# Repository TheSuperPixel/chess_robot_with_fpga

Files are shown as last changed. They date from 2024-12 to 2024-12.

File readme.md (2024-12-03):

# FPGA三子棋机器人
## 简介
这是我们用纯Verilog制作的三子棋机器人，参加全国大学生芯片与系统设计大赛FPGA赛道获得一等奖。机器主要由图像识别部分，下棋预测部分和电机驱动部分组成，机器能够保证在与玩家对战过程中，机器一方不会落败。玩家下棋后，机器摄像头自动识别棋子位置，通过我们编写的verilog算法自动计算下一步下棋位置，随后控制步进电机夹取棋子和玩家对弈。此外，还支持电机自动校准复位，棋子自动复位，触摸屏可视化调颜色阈值，LCD屏幕实时显示处理前后图像和棋局状态等功能。系统结构图如下图所示：
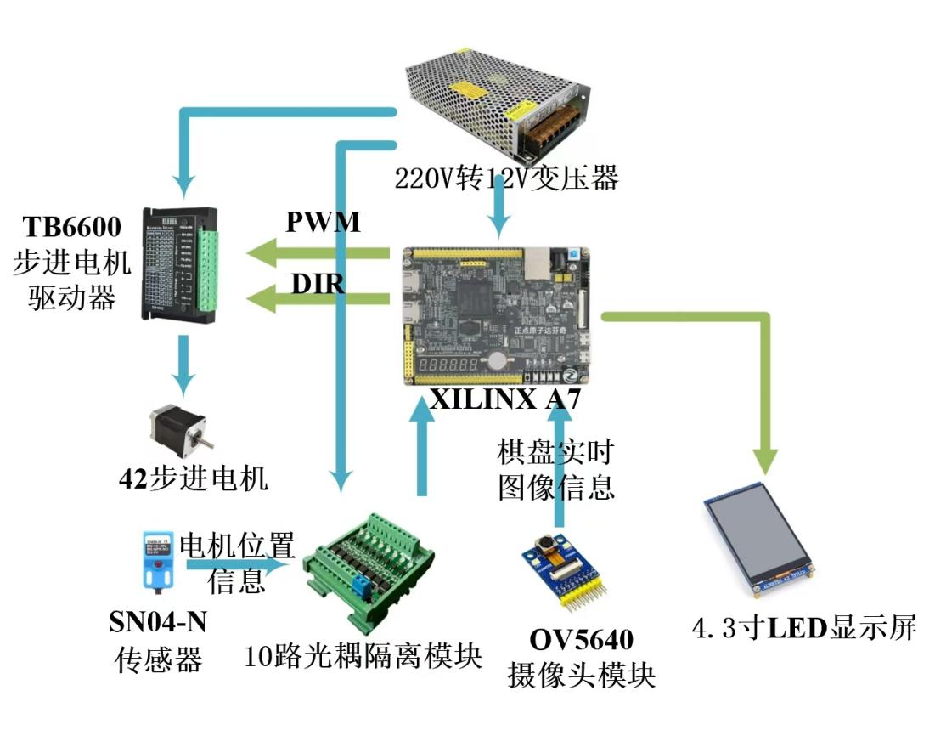
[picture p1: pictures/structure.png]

## 演示视频
https://www.bilibili.com/video/BV1N1zCYzEWG
## 使用方法
1.参考上面的系统结构图工程代码的xdc文件搭建电路，电机驱动模块和其他电路，SN04-4传感器的电源接12V电压，输出信号使用12V转3.3V的光耦隔离模块来转换成3.3V电压供FPGA读取，OV5640和LCD模块连接方法参考达芬奇开发板教程，步进电机驱动器的接法和网上常用接法一致。
2.下载程序，如果摄像头的ROI区域位置和大小与实际有偏差，或者需要调节颜色阈值范围，可以在VIO里面进行手动调节。
## 参考资料
[1] 手把手教你学达芬奇&达芬奇Pro之FPGA开发篇【真人出镜】FPGA教学视频教程. (n.d.). Retrieved November 11, 2024, from https://www.bilibili.com/video/BV1E94y1p7jk
[2] 正点原子手把手教你学FPGA-基于达芬奇Pro开发板 Artix-7 XC7A35T/XC7A100T. (n.d.). Retrieved November 11, 2024, from https://www.bilibili.com/video/BV19A411N7L3
[3] C语言实现“井字棋”游戏（三子棋）人机对弈. (2020, January 1). CSDN. Retrieved November 11, 2024, from https://blog.csdn.net/qq_58284486/article/details/122270775

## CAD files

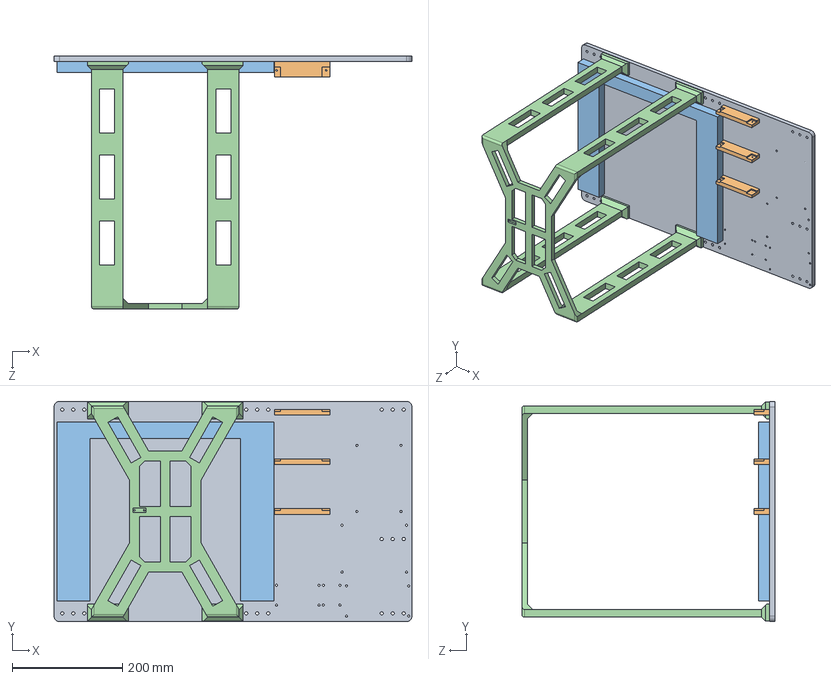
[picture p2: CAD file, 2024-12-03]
龙门架/装配体2.SLDASM
650.0 x 400.0 x 460.0 mm
龙门架底板
电机驱动固定 x 3
龙门架边框
摄像头支架

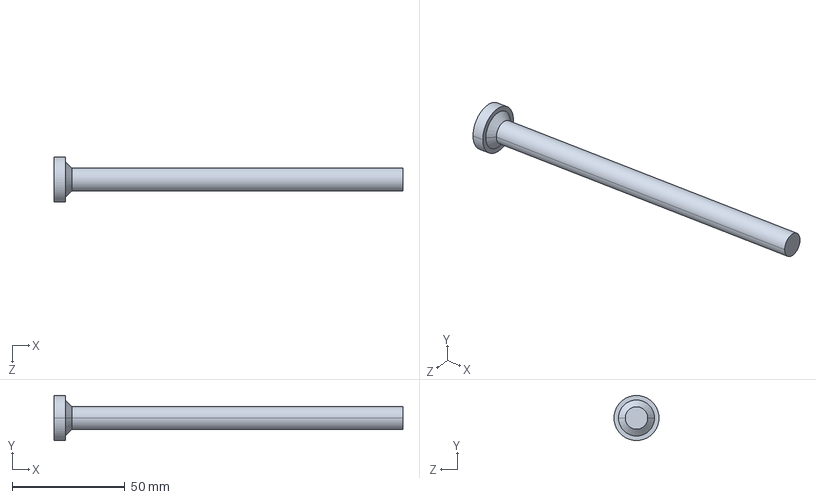
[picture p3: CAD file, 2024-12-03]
龙门架/电磁铁棒子打印.STEP
155.0 x 20.0 x 20.0 mm

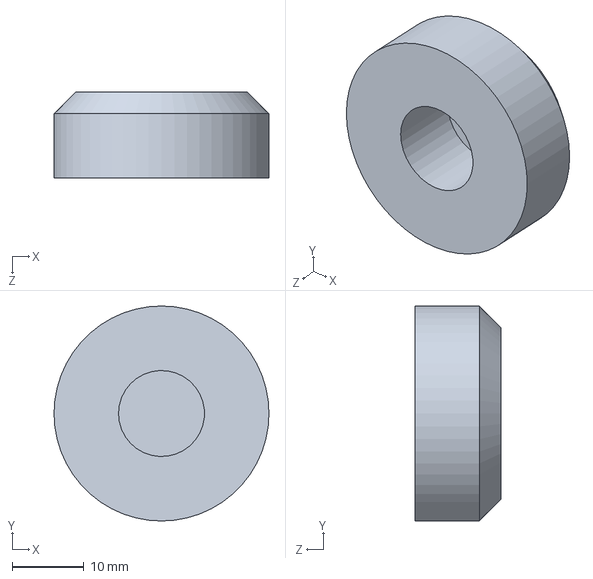
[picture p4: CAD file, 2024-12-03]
龙门架/棋子.SLDPRT
30.0 x 30.0 x 12.0 mm

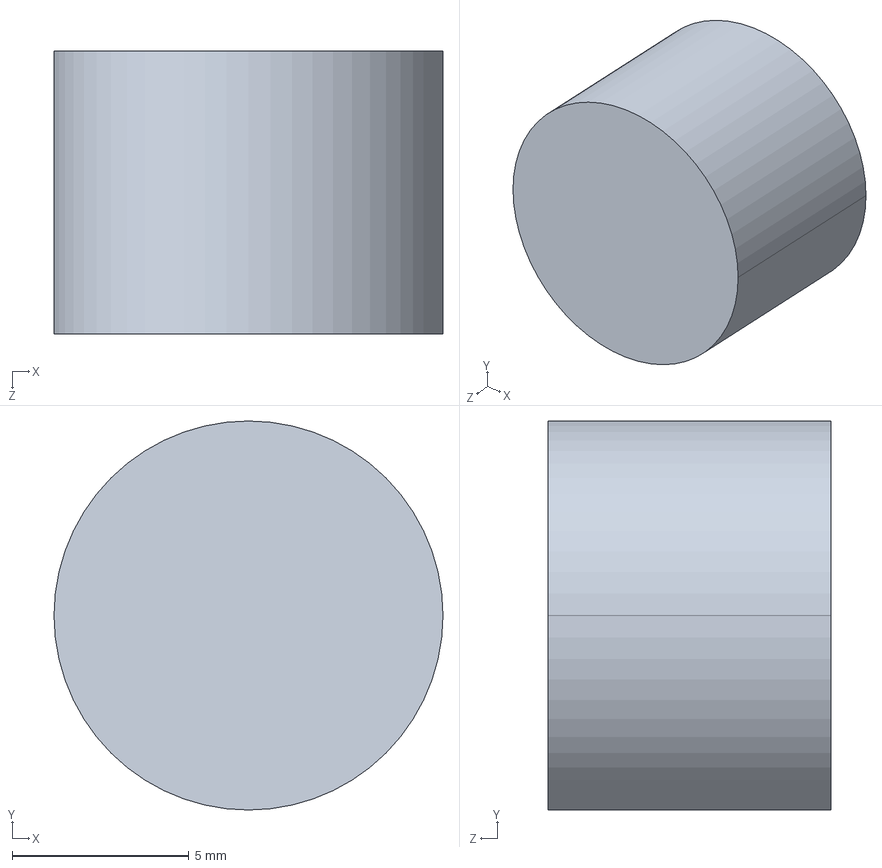
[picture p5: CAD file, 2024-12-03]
龙门架/磁铁固定打印.STEP
11.0 x 11.0 x 8.00 mm

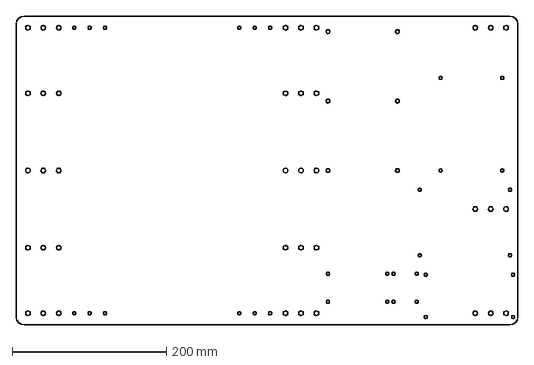
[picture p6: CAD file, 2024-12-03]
龙门架/龙门架底板2.DXF
650.0 x 400.0 mm

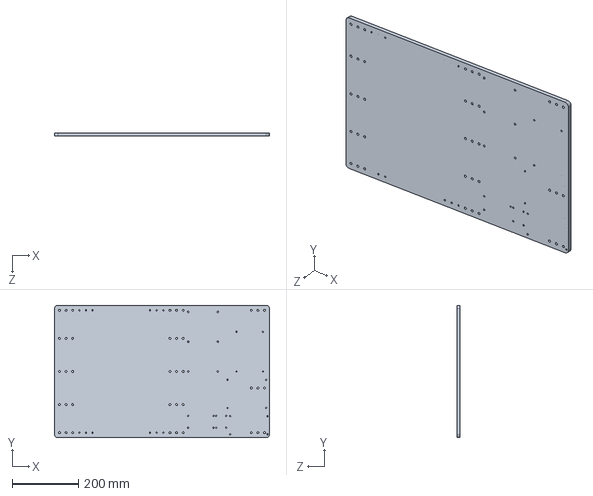
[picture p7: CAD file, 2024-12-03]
龙门架/龙门架底板.SLDPRT
650.0 x 400.0 x 10.0 mm

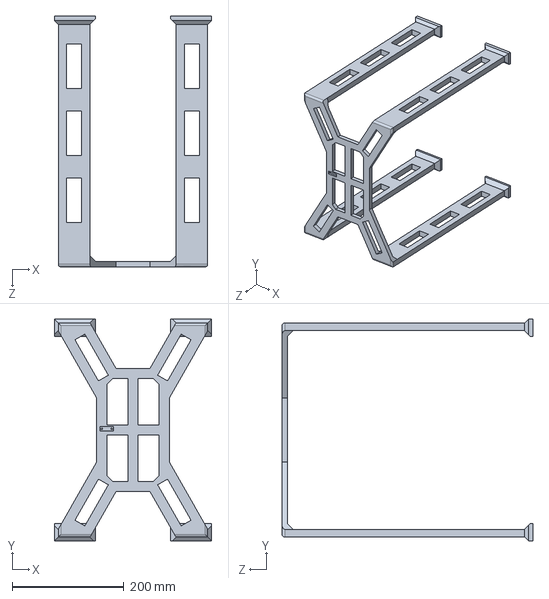
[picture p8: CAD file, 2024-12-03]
龙门架/摄像头支架.SLDPRT
282.0 x 398.0 x 450.0 mm

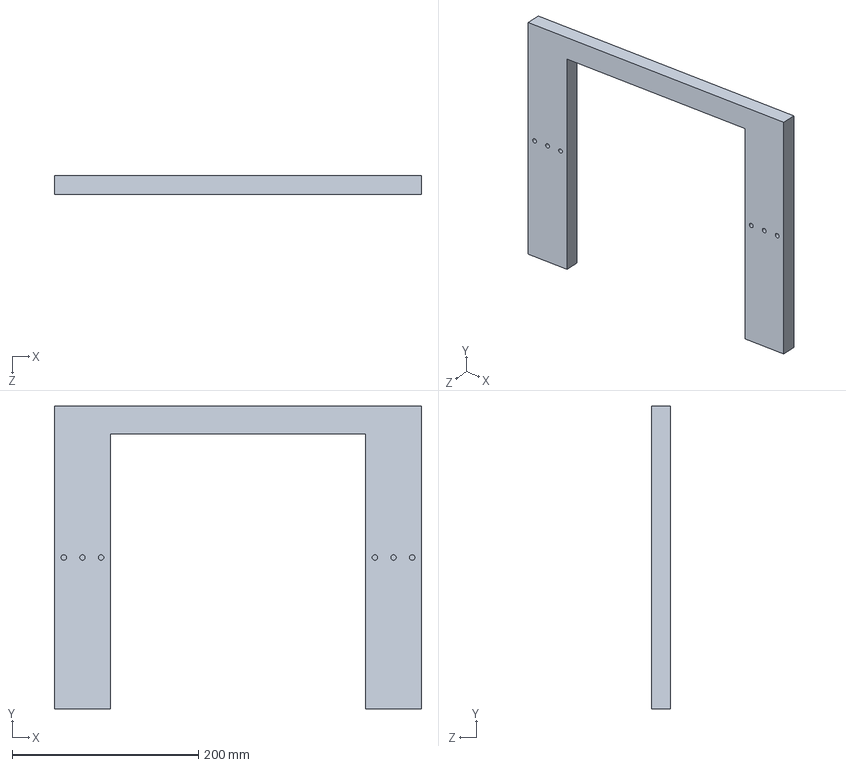
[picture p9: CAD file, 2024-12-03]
龙门架/龙门架边框.SLDPRT
394.0 x 325.0 x 20.0 mm

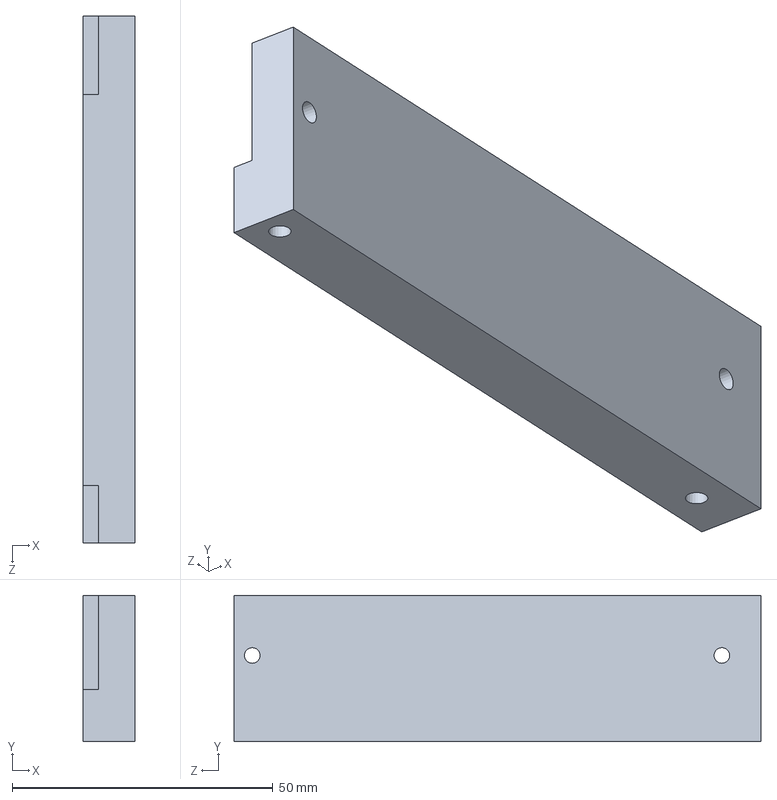
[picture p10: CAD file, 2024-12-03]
龙门架/电机驱动固定.SLDPRT
10.0 x 28.0 x 101.0 mm

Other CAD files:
龙门架/棋子打印.STEP
龙门架/磁铁固定.SLDPRT
龙门架/电磁铁棒子.SLDPRT
龙门架/电机驱动固定打印.STEP
龙门架/龙门架底板.DXF

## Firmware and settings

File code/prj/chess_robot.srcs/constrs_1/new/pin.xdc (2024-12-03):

create_clock -period 20.000 -name sys_clk [get_ports sys_clk]
set_property PACKAGE_PIN R4 [get_ports sys_clk]
set_property IOSTANDARD LVCMOS33 [get_ports sys_clk]
set_property IOSTANDARD LVCMOS33 [get_ports sys_rst_n]
set_property PACKAGE_PIN U2 [get_ports sys_rst_n]

#RGB LCD
set_property -dict {PACKAGE_PIN R16 IOSTANDARD LVCMOS33} [get_ports {lcd_rgb[0]}]
set_property -dict {PACKAGE_PIN P15 IOSTANDARD LVCMOS33} [get_ports {lcd_rgb[1]}]
set_property -dict {PACKAGE_PIN R14 IOSTANDARD LVCMOS33} [get_ports {lcd_rgb[2]}]
set_property -dict {PACKAGE_PIN P14 IOSTANDARD LVCMOS33} [get_ports {lcd_rgb[3]}]
set_property -dict {PACKAGE_PIN N14 IOSTANDARD LVCMOS33} [get_ports {lcd_rgb[4]}]
set_property -dict {PACKAGE_PIN N13 IOSTANDARD LVCMOS33} [get_ports {lcd_rgb[5]}]
set_property -dict {PACKAGE_PIN V9 IOSTANDARD LVCMOS33} [get_ports {lcd_rgb[6]}]
set_property -dict {PACKAGE_PIN W9 IOSTANDARD LVCMOS33} [get_ports {lcd_rgb[7]}]
set_property -dict {PACKAGE_PIN U18 IOSTANDARD LVCMOS33} [get_ports {lcd_rgb[8]}]
set_property -dict {PACKAGE_PIN U17 IOSTANDARD LVCMOS33} [get_ports {lcd_rgb[9]}]
set_property -dict {PACKAGE_PIN V19 IOSTANDARD LVCMOS33} [get_ports {lcd_rgb[10]}]
set_property -dict {PACKAGE_PIN T18 IOSTANDARD LVCMOS33} [get_ports {lcd_rgb[11]}]
set_property -dict {PACKAGE_PIN V20 IOSTANDARD LVCMOS33} [get_ports {lcd_rgb[12]}]
set_property -dict {PACKAGE_PIN R18 IOSTANDARD LVCMOS33} [get_ports {lcd_rgb[13]}]
set_property -dict {PACKAGE_PIN N17 IOSTANDARD LVCMOS33} [get_ports {lcd_rgb[14]}]
set_property -dict {PACKAGE_PIN P17 IOSTANDARD LVCMOS33} [get_ports {lcd_rgb[15]}]
set_property -dict {PACKAGE_PIN AB18 IOSTANDARD LVCMOS33} [get_ports {lcd_rgb[16]}]
set_property -dict {PACKAGE_PIN AA18 IOSTANDARD LVCMOS33} [get_ports {lcd_rgb[17]}]
set_property -dict {PACKAGE_PIN Y19 IOSTANDARD LVCMOS33} [get_ports {lcd_rgb[18]}]
set_property -dict {PACKAGE_PIN Y18 IOSTANDARD LVCMOS33} [get_ports {lcd_rgb[19]}]
set_property -dict {PACKAGE_PIN W20 IOSTANDARD LVCMOS33} [get_ports {lcd_rgb[20]}]
set_property -dict {PACKAGE_PIN W17 IOSTANDARD LVCMOS33} [get_ports {lcd_rgb[21]}]
set_property -dict {PACKAGE_PIN V18 IOSTANDARD LVCMOS33} [get_ports {lcd_rgb[22]}]
set_property -dict {PACKAGE_PIN V17 IOSTANDARD LVCMOS33} [get_ports {lcd_rgb[23]}]
set_property -dict {PACKAGE_PIN V8 IOSTANDARD LVCMOS33} [get_ports lcd_hs]
set_property -dict {PACKAGE_PIN U7 IOSTANDARD LVCMOS33} [get_ports lcd_vs]
set_property -dict {PACKAGE_PIN AB7 IOSTANDARD LVCMOS33} [get_ports lcd_de]
set_property -dict {PACKAGE_PIN V7 IOSTANDARD LVCMOS33} [get_ports lcd_bl]
set_property -dict {PACKAGE_PIN Y9 IOSTANDARD LVCMOS33} [get_ports lcd_pclk]
set_property -dict {PACKAGE_PIN W7 IOSTANDARD LVCMOS33} [get_ports lcd_rst]

#LCD TOUCH
set_property -dict {PACKAGE_PIN Y8 IOSTANDARD LVCMOS33} [get_ports touch_scl]
set_property -dict {PACKAGE_PIN AB8 IOSTANDARD LVCMOS33} [get_ports touch_sda]
set_property -dict {PACKAGE_PIN Y7 IOSTANDARD LVCMOS33} [get_ports touch_int]
set_property -dict {PACKAGE_PIN AB6 IOSTANDARD LVCMOS33} [get_ports touch_rst_n]

#CAMERA

#摄像头接口的时钟
create_clock -period 20.000 -name cmos_pclk [get_ports cam_pclk]
set_property CLOCK_DEDICATED_ROUTE FALSE [get_nets cam_pclk_IBUF]
set_property -dict {PACKAGE_PIN F14 IOSTANDARD LVCMOS33} [get_ports cam_pclk]
set_property -dict {PACKAGE_PIN C15 IOSTANDARD LVCMOS33} [get_ports cam_rst_n]
set_property -dict {PACKAGE_PIN F16 IOSTANDARD LVCMOS33} [get_ports cam_pwdn]
set_property -dict {PACKAGE_PIN C14 IOSTANDARD LVCMOS33 IOB TRUE} [get_ports {cam_data[0]}]
set_property -dict {PACKAGE_PIN B13 IOSTANDARD LVCMOS33 IOB TRUE} [get_ports {cam_data[1]}]
set_property -dict {PACKAGE_PIN C13 IOSTANDARD LVCMOS33 IOB TRUE} [get_ports {cam_data[2]}]
set_property -dict {PACKAGE_PIN D15 IOSTANDARD LVCMOS33 IOB TRUE} [get_ports {cam_data[3]}]
set_property -dict {PACKAGE_PIN D14 IOSTANDARD LVCMOS33 IOB TRUE} [get_ports {cam_data[4]}]
set_property -dict {PACKAGE_PIN E14 IOSTANDARD LVCMOS33 IOB TRUE} [get_ports {cam_data[5]}]
set_property -dict {PACKAGE_PIN E13 IOSTANDARD LVCMOS33 IOB TRUE} [get_ports {cam_data[6]}]
set_property -dict {PACKAGE_PIN F13 IOSTANDARD LVCMOS33 IOB TRUE} [get_ports {cam_data[7]}]
set_property -dict {PACKAGE_PIN E16 IOSTANDARD LVCMOS33} [get_ports cam_vsync]
set_property -dict {PACKAGE_PIN B15 IOSTANDARD LVCMOS33} [get_ports cam_href]
set_property -dict {PACKAGE_PIN D16 IOSTANDARD LVCMOS33} [get_ports cam_scl]
set_property -dict {PACKAGE_PIN B16 IOSTANDARD LVCMOS33} [get_ports cam_sda]

#---------------------------------TB6600_X----------------------------------------
set_property -dict {PACKAGE_PIN J17 IOSTANDARD LVCMOS33} [get_ports dir_out_x]
set_property -dict {PACKAGE_PIN K18 IOSTANDARD LVCMOS33} [get_ports pwm_out_x]

##---------------------------------TB6600_Y----------------------------------------
set_property -dict {PACKAGE_PIN L20 IOSTANDARD LVCMOS33} [get_ports dir_out_y]
set_property -dict {PACKAGE_PIN L19 IOSTANDARD LVCMOS33} [get_ports pwm_out_y]
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

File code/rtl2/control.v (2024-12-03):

// Descriptions:        电机目标位置计算

module control (
    input           sys_clk,
    input           sys_rst_n,
    input           motor_ready_x,
    input           motor_ready_y,
    input           motor_ready_z,

    input  [2:0]  motor_start_pos,
    input  [3:0]  motor_end_pos,
    input         motor_start,

    input  [3:0]  motor_start_pos2,
    input  [3:0]  motor_end_pos2,
    input         motor_start2,

    output  [15:0]  goal_pulse_x,
    output  [15:0]  goal_pulse_y,
    output  [15:0]  goal_pulse_z,
    output  reg     catch_en,
    output          motor_program_done
);
assign motor_program_done = (motor_program_cnt == 4'd10)? 1:0; 

wire [15:0] goal_pulse_x_handset;
wire [15:0] goal_pulse_y_handset;
wire [15:0] goal_pulse_z_handset;
reg [15:0] goal_pulse_x_auto;
reg [15:0] goal_pulse_y_auto;
reg [15:0] goal_pulse_z_auto;

wire goal_pulse_handset_en;

assign goal_pulse_x = (goal_pulse_handset_en == 1'b1) ? goal_pulse_x_handset : goal_pulse_x_auto;
assign goal_pulse_y = (goal_pulse_handset_en == 1'b1) ? goal_pulse_y_handset : goal_pulse_y_auto;
assign goal_pulse_z = (goal_pulse_handset_en == 1'b1) ? goal_pulse_z_handset : goal_pulse_z_auto;

vio_3 motor_control_vio (
  .clk(sys_clk),                // input wire clk
  .probe_out0(goal_pulse_x_handset),  // output wire [15 : 0] probe_out0
  .probe_out1(goal_pulse_y_handset),  // output wire [15 : 0] probe_out1
  .probe_out2(goal_pulse_z_handset),  // output wire [15 : 0] probe_out2
  .probe_out3(goal_pulse_handset_en)  // output wire [0 : 0] probe_out3
);

reg [28:0] motor_program_clk_cnt;
always @(posedge sys_clk or negedge sys_rst_n) begin
    if (!sys_rst_n) begin
        motor_program_clk_cnt<=0;
    end
    else if (motor_program_clk_cnt<28'd1000_0000) begin
        motor_program_clk_cnt<=motor_program_clk_cnt+1'b1;
    end
    else 
        motor_program_clk_cnt<=0;
end

reg motor_program_clk;
always @(posedge sys_clk or negedge sys_rst_n) begin
    if (!sys_rst_n) 
        motor_program_clk<=1'b0;
    else if (motor_program_clk_cnt>28'd500_0000)
        motor_program_clk<=1'b1;
    else
        motor_program_clk<=1'b0;
end

wire motor_ready_all;
assign motor_ready_all = motor_ready_x & motor_ready_y & motor_ready_z;

reg  [3:0] motor_program_cnt;

reg  [48:0] all_program [64:0];

always @(posedge motor_program_clk or negedge sys_rst_n) begin
    if (!sys_rst_n) begin
        motor_program_cnt<=0;
        all_program[4'd0] <=49'h0_8000_8000_8000;
        all_program[4'd1] <=49'h0_8000_8000_8000;
        all_program[4'd2] <=49'h0_8000_8000_8000;
        all_program[4'd3] <=49'h0_8000_8000_8000;
        all_program[4'd4] <=49'h0_8000_8000_8000;
        all_program[4'd5] <=49'h0_8000_8000_8000;
        all_program[4'd6] <=49'h0_8000_8000_8000;
        all_program[4'd7] <=49'h0_8000_8000_8000;
        goal_pulse_x_auto <=49'h0_8000_8000_8000;
        goal_pulse_y_auto <=49'h0_8000_8000_8000;
        goal_pulse_z_auto <=49'h0_8000_8000_8000;
    end
    else if(motor_start==1'b1)begin
        case (motor_start_pos)
            0:begin
                all_program[4'd0] <=49'h0_B900_2250_8800;//第1个存储抬起
                all_program[4'd1] <=49'h0_B900_2250_8800;//第1个存储抬起
                all_program[4'd2] <=49'h0_B900_2250_8800;//第1个存储抬起
                all_program[4'd3] <=49'h0_B900_2250_8800;//第1个存储抬起
            end
            1:begin
                //第1个存储
                all_program[4'd0] <=49'h0_B900_2250_8800;//第1个存储抬起
                all_program[4'd1] <=49'h0_B900_2250_6D80;//第1个存储放下
                all_program[4'd2] <=49'h1_B900_2250_6D80;//第1个磁吸开
                all_program[4'd3] <=49'h1_B900_2250_8800;//第1个存储抬起
            end 
            2:begin
                //第2个存储
                all_program[4'd0] <=49'h0_B900_3D50_8800;//第2个存储抬起
                all_program[4'd1] <=49'h0_B900_3D50_6D80;//第2个存储放下
                all_program[4'd2] <=49'h1_B900_3D50_6D80;//第2个磁吸开
                all_program[4'd3] <=49'h1_B900_3D50_8800;//第2个存储抬起
            end
            3:begin
                //第3个存储
                all_program[4'd0] <=49'h0_9900_2250_8800;//第3个存储抬起
                all_program[4'd1] <=49'h0_9900_2250_6D80;//第3个存储放下
                all_program[4'd2] <=49'h1_9900_2250_6D80;//第3个磁吸开
                all_program[4'd3] <=49'h1_9900_2250_8800;//第3个存储抬起
            end
            4:begin
                //第4个存储
                all_program[4'd0] <=49'h0_9900_3A50_8800;//第4个存储抬起
                all_program[4'd1] <=49'h0_9900_3A50_6D80;//第4个存储放下
                all_program[4'd2] <=49'h1_9900_3A50_6D80;//第4个磁吸开
                all_program[4'd3] <=49'h1_9900_3A50_8800;//第4个存储抬起
            end
            default: ;
        endcase
        case (motor_end_pos)
            0: begin
                all_program[4'd4] <=49'h0_B900_2250_8800;//第1个存储抬起
                all_program[4'd5] <=49'h0_B900_2250_8800;//第1个存储抬起
                all_program[4'd6] <=49'h0_B900_2250_8800;//第1个存储抬起
                all_program[4'd7] <=49'h0_B900_2250_8800;//第1个存储抬起
                all_program[4'd8] <=49'h0_B900_2250_8800;//第1个存储抬起
                all_program[4'd9] <=49'h0_B900_2250_8800;//第1个存储抬起
                all_program[4'd10] <=49'h0_B900_2250_8800;//第1个存储抬起
            end
            1: begin
                //第1个下棋
                all_program[4'd4] <=49'h1_B500_6C00_8800;//第1个下棋抬起
                all_program[4'd5] <=49'h1_B500_6C00_6E80;//第1个下棋放下
                all_program[4'd6] <=49'h0_B500_6C00_6E80;//第1个磁吸关
                all_program[4'd7] <=49'h0_B500_6C00_8800;//第1个下棋抬起
                all_program[4'd8] <=49'h0_B900_2250_8800;//第1个存储抬起
                all_program[4'd9] <=49'h0_B900_2250_8800;//第1个存储抬起
                all_program[4'd10] <=49'h0_B900_2250_8800;//第1个存储抬起
            end
            2: begin
                //第2个下棋
                all_program[4'd4] <=49'h1_B500_8C00_8800;//第2个下棋抬起
                all_program[4'd5] <=49'h1_B500_8C00_6E80;//第2个下棋放下
                all_program[4'd6] <=49'h0_B500_8C00_6E80;//第2个磁吸关
                all_program[4'd7] <=49'h0_B500_8C00_8800;//第2个下棋抬起
                all_program[4'd8] <=49'h0_B900_2250_8800;//第1个存储抬起
                all_program[4'd9] <=49'h0_B900_2250_8800;//第1个存储抬起
                all_program[4'd10] <=49'h0_B900_2250_8800;//第1个存储抬起
            end
            3: begin
                //第3个下棋
                all_program[4'd4] <=49'h1_B500_AC00_8800;//第3个下棋抬起
                all_program[4'd5] <=49'h1_B500_AC00_6E80;//第3个下棋放下
                all_program[4'd6] <=49'h0_B500_AC00_6E80;//第3个磁吸关
                all_program[4'd7] <=49'h0_B500_AC00_8800;//第3个下棋抬起
                all_program[4'd8] <=49'h0_B900_2250_8800;//第1个存储抬起
                all_program[4'd9] <=49'h0_B900_2250_8800;//第1个存储抬起
                all_program[4'd10] <=49'h0_B900_2250_8800;//第1个存储抬起
            end
            4: begin
                //第4个下棋
                all_program[4'd4] <=49'h1_9000_6C00_8800;//第4个下棋抬起
                all_program[4'd5] <=49'h1_9000_6C00_6E80;//第4个下棋放下
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

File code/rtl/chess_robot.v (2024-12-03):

// Descriptions:       chess_robot

module chess_robot(    
    input                 sys_clk      ,  //系统时钟
    input                 sys_rst_n    ,  //系统复位，低电平有效
    //摄像头接口                       
    input                 cam_pclk     ,  //cmos 数据像素时钟
    input                 cam_vsync    ,  //cmos 场同步信号
    input                 cam_href     ,  //cmos 行同步信号
    input   [7:0]         cam_data     ,  //cmos 数据
    output                cam_rst_n    ,  //cmos 复位信号，低电平有效
    output                cam_pwdn ,      //电源休眠模式选择 0：正常模式 1：电源休眠模式
    output                cam_scl      ,  //cmos SCCB_SCL线
    inout                 cam_sda      ,  //cmos SCCB_SDA线       
    // DDR3                            
    inout   [15:0]        ddr3_dq      ,  //DDR3 数据
    inout   [1:0]         ddr3_dqs_n   ,  //DDR3 dqs负
    inout   [1:0]         ddr3_dqs_p   ,  //DDR3 dqs正  
    output  [13:0]        ddr3_addr    ,  //DDR3 地址   
    output  [2:0]         ddr3_ba      ,  //DDR3 banck 选择
    output                ddr3_ras_n   ,  //DDR3 行选择
    output                ddr3_cas_n   ,  //DDR3 列选择
    output                ddr3_we_n    ,  //DDR3 读写选择
    output                ddr3_reset_n ,  //DDR3 复位
    output  [0:0]         ddr3_ck_p    ,  //DDR3 时钟正
    output  [0:0]         ddr3_ck_n    ,  //DDR3 时钟负
    output  [0:0]         ddr3_cke     ,  //DDR3 时钟使能
    output  [0:0]         ddr3_cs_n    ,  //DDR3 片选
    output  [1:0]         ddr3_dm      ,  //DDR3_dm
    output  [0:0]         ddr3_odt     ,  //DDR3_odt									   
    //lcd接口                           
    output                lcd_hs       ,  //LCD 行同步信号
    output                lcd_vs       ,  //LCD 场同步信号
    output                lcd_de       ,  //LCD 数据输入使能
    inout       [23:0]    lcd_rgb      ,  //LCD 颜色数据
    output                lcd_bl       ,  //LCD 背光控制信号
    output                lcd_rst      ,  //LCD 复位信号
    output                lcd_pclk     ,  //LCD 采样时钟
    
    //my
    input                 key1,

    input   [2:0]   signial_x,
    input   [2:0]   signial_y,
    input   [2:0]   signial_z,

    output dir_out_x,
    output dir_out_y,
    output dir_out_z,
    output pwm_out_x,
    output pwm_out_y,
    output pwm_out_z,

    output catch_en,
    output led1_equal,
    output led2_player_win,
    output led3_machine_win,

    //TOUCH 接口                  
    inout            touch_sda  ,  //TOUCH IIC数据
    output           touch_scl  ,  //TOUCH IIC时钟
    inout            touch_int  ,  //TOUCH INT信号
    output           touch_rst_n  //TOUCH 复位信号

    );                                 
									   							   
//wire define                          
wire         clk_50m                   ;  //50mhz时钟,提供给lcd驱动时钟
wire         locked                    ;  //时钟锁定信号
wire         rst_n                     ;  //全局复位 								    )          				    
wire         wr_en                     ;  //DDR3控制器模块写使能
wire  [15:0] wr_data                   ;  //DDR3控制器模块写数据
wire         rdata_req                 ;  //DDR3控制器模块读使能
wire  [15:0] rd_data                   ;  //DDR3控制器模块读数据
wire         cmos_frame_valid          ;  //数据有效使能信号
wire         init_calib_complete       ;  //DDR3初始化完成init_calib_complete
wire         sys_init_done             ;  //系统初始化完成(DDR初始化+摄像头初始化)
wire         clk_200m                  ;  //ddr3参考时钟
wire         cmos_frame_vsync          ;  //输出帧有效场同步信号
wire         cmos_frame_href           ;  //输出帧有效行同步信号 
wire         lcd_clk                   ;  //分频产生的LCD 采样时钟
wire  [12:0] h_disp                    ;  //LCD屏水平分辨率
wire  [12:0] v_disp                    ;  //LCD屏垂直分辨率     
wire  [10:0] h_pixel                   ;  //存入ddr3的水平分辨率        
wire  [10:0] v_pixel                   ;  //存入ddr3的屏垂直分辨率
wire  [12:0] y_addr_st                 ; 
wire  [12:0] y_addr_end                ; 
wire  [15:0] lcd_id                    ;  //LCD屏的ID号
wire  [27:0] ddr3_addr_max             ;  //存入DDR3的最大读写地址 
wire  [12:0] total_h_pixel             ;  //水平总像素大小 
wire  [12:0] total_v_pixel             ;  //垂直总像素大小
wire  [15:0] post_rgb                  ;  //处理后的图像数据
wire         post_frame_vsync          ;  //处理后的场信号
wire         post_frame_de             ;  //处理后的数据有效使能 
wire  [10:0] pixel_xpos                ;  //像素点横坐标
wire  [10:0] pixel_ypos                ;  //像素点纵坐标  
//*****************************************************
//**                    main code
//*****************************************************
//待时钟锁定后产生复位结束信号
assign  rst_n = sys_rst_n & locked;

//系统初始化完成：DDR3初始化完成
assign  sys_init_done = init_calib_complete;

//摄像头图像分辨率设置模块
picture_size u_picture_size (
    .rst_n              (rst_n),
    .clk                (clk_50m  ),    
    .lcd_id             (lcd_id),           //LCD的器件ID
                        
    .cmos_h_pixel       (h_disp  ),         //摄像头水平分辨率
    .cmos_v_pixel       (v_disp  ),         //摄像头垂直分辨率  
    .total_h_pixel      (total_h_pixel ),   //水平总像素大小
    .total_v_pixel      (total_v_pixel ),   //垂直总像素大小
    .y_addr_st          (y_addr_st ), 
    .y_addr_end         (y_addr_end),
    .ddr3_addr_max      (ddr3_addr_max)     //ddr3最大读写地址
    );
   
 //ov5640 驱动
ov5640_dri u_ov5640_dri(
    .clk               (clk_50m),
    .rst_n             (rst_n),

    .cam_pclk          (cam_pclk ),
    .cam_vsync         (cam_vsync),
    .cam_href          (cam_href ),
    .cam_data          (cam_data ),
    .cam_rst_n         (cam_rst_n),
    .cam_pwdn          (cam_pwdn ),
    .cam_scl           (cam_scl  ),
    .cam_sda           (cam_sda  ),
    
    .capture_start     (init_calib_complete),
    .cmos_h_pixel      (h_disp),
    .cmos_v_pixel      (v_disp),
    .total_h_pixel     (total_h_pixel),
    .total_v_pixel     (total_v_pixel),
    .y_addr_st         (y_addr_st ), 
    .y_addr_end        (y_addr_end),
    .cmos_frame_vsync  (cmos_frame_vsync),
    .cmos_frame_href   (cmos_frame_href),
    .cmos_frame_valid  (cmos_frame_valid),
    .cmos_frame_data   (wr_data)
    );  
    
 //图像处理模块
vip u_vip(
    //module clock
    .clk                   (cam_pclk),          // 时钟信号
    .rst_n                 (rst_n ),            // 复位信号（低有效）
    //图像处理前的数据接口
    .pre_frame_vsync       (cmos_frame_vsync),
    .pre_frame_href        (cmos_frame_href),
    .pre_frame_de          (cmos_frame_valid),
    .pre_rgb               (wr_data),
    //图像处理后的数据接口
    .post_frame_vsync      (post_frame_vsync),  // 处理后的场信号
    .post_frame_href       ( ),                 // 处理后的行信号
    .post_frame_de         (post_frame_de),     // 处理后的数据有效使能 
    .post_rgb              (post_rgb),           // 处理后的图像数据

    .my_threshold_y_up_touch    (my_threshold_y_up_touch   ),
    .my_threshold_y_down_touch  (my_threshold_y_down_touch ),
    .my_threshold_cb_up_touch   (my_threshold_cb_up_touch  ),
    .my_threshold_cb_down_touch (my_threshold_cb_down_touch),
    .my_threshold_cr_up_touch   (my_threshold_cr_up_touch  ),
    .my_threshold_cr_down_touch (my_threshold_cr_down_touch)
);
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
